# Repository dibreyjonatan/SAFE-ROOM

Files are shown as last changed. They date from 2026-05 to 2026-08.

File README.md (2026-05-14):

# SAFE-ROOM
SAFE ROOM est une dispositif électronique qui permet de connaitre en temps réel, les conditions d'une pièce. A savoir la qualité d'air, la temperature, l'humidité, et la pression.  Ce projet intègre également une antenne bluetooth qui permet de transmettre sur une platform les données capteur.

# SCHEMATIQUE DU PROJET
La schématique a été réalisé avec KiCAD 9.0
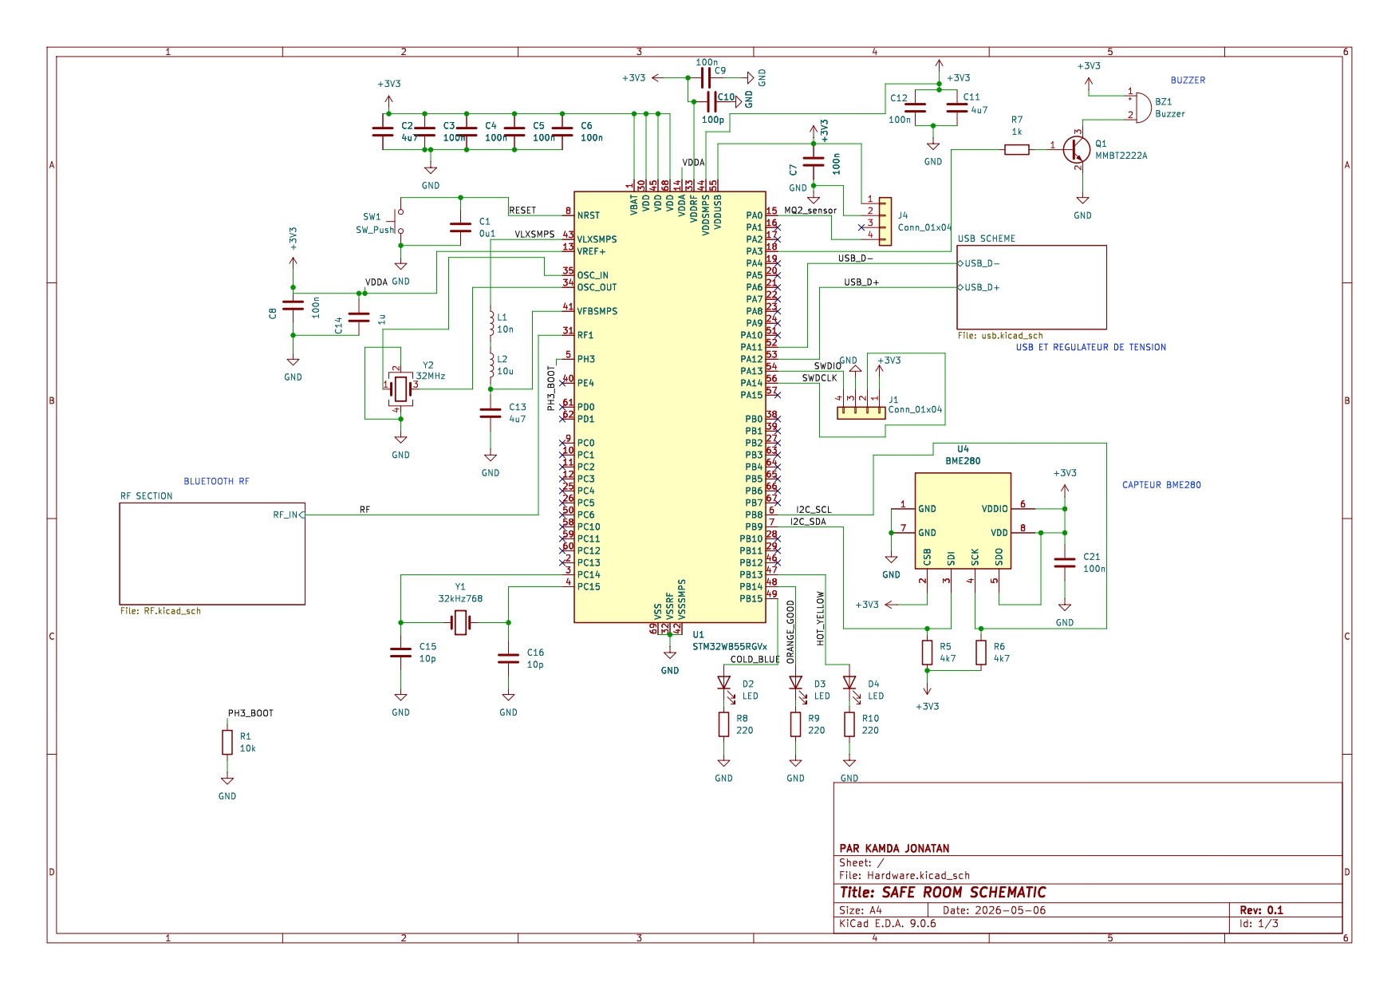
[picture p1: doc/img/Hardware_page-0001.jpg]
schematic_system

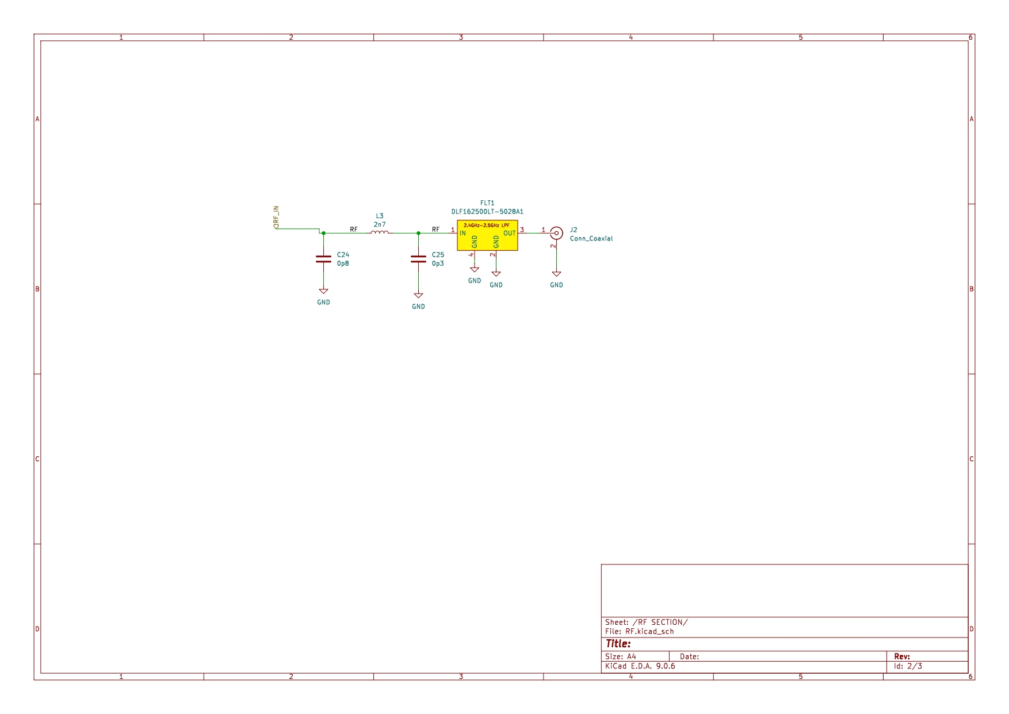
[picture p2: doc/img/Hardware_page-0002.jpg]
schematic_rf

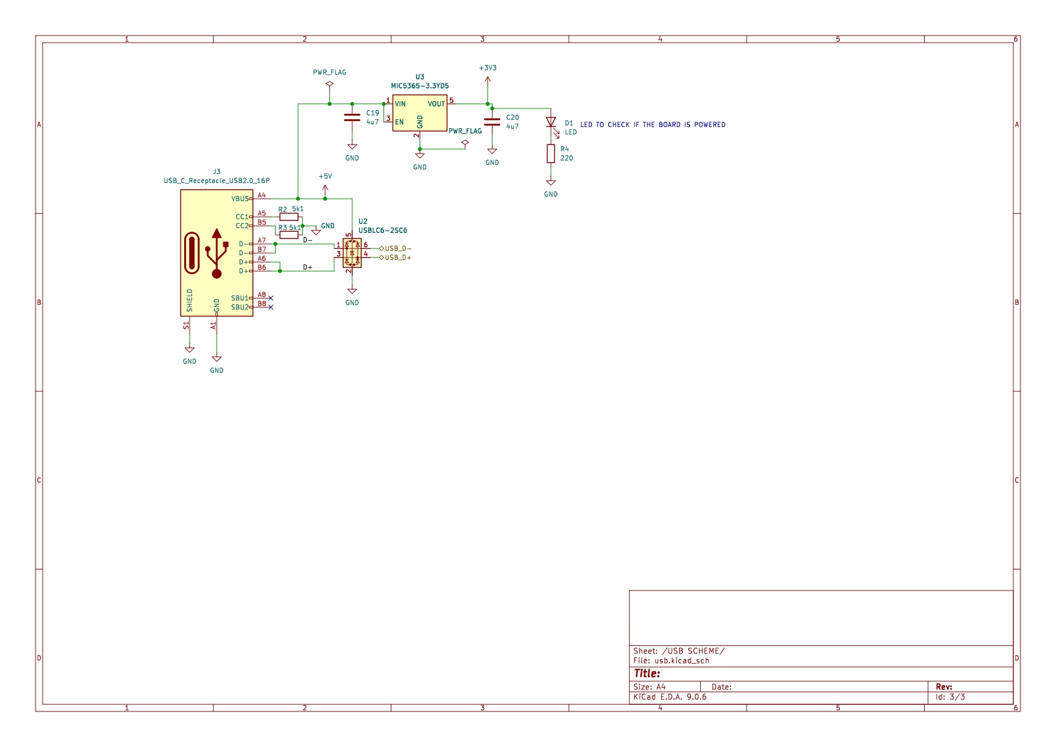
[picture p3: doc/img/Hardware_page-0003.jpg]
schematic_usb


# CARTE SAFE ROOM
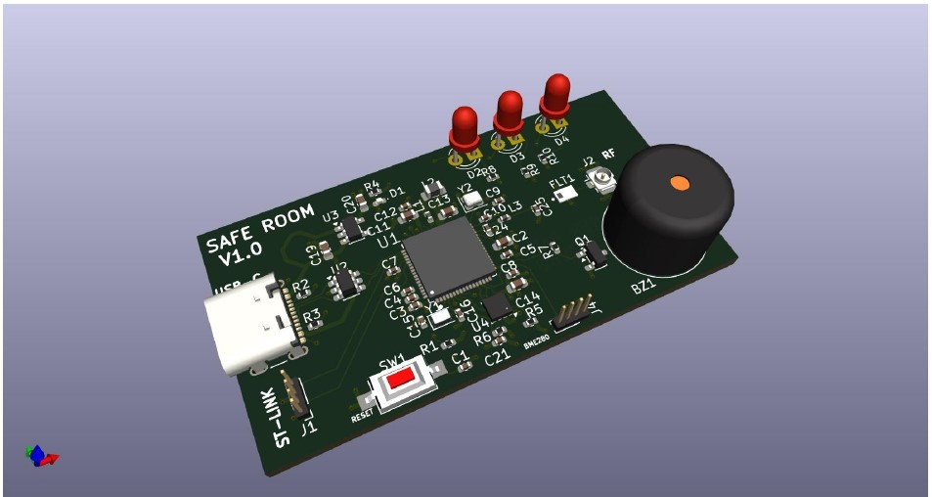
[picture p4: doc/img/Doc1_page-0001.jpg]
pcb_finale


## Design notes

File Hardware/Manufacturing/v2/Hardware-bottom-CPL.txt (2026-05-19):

### Footprint positions - created on 2026-05-17T01:28:31+0200 ###
### Printed by KiCad version 9.0.6
## Unit = mm, Angle = deg.
## Side : bottom
# Ref     Val       Package                PosX       PosY       Rot  Side
## End

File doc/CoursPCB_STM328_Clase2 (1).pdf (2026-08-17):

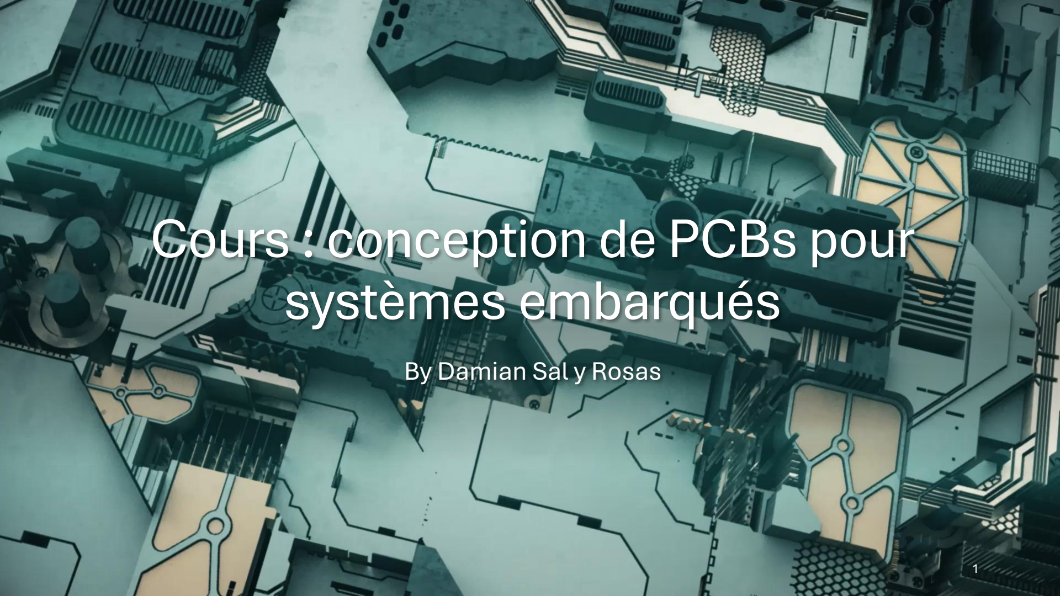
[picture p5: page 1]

# Cours : conception de PCBs pour systèmes embarqués

## By Damian Sal y Rosas

# Carte PCB à concevoir

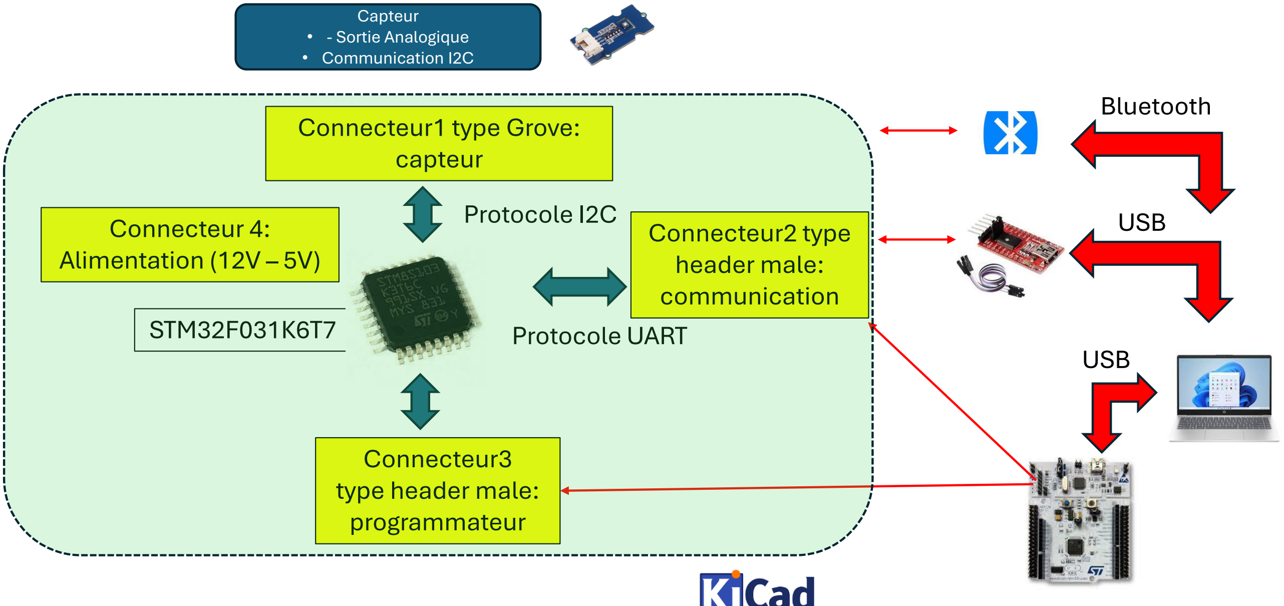
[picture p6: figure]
STM32F031K6T7; Connecteur1 type Grove: capteur; Protocole I2C; Protocole UART; Connecteur2 type header male: communication; Connecteur3 type header male: programmateur; USB; Connecteur 4: Alimentation (12V – 5V); Capteur • - Sortie Analogique • Communication I2C; Bluetooth

# Carte PCB à concevoir - Dimensionnes

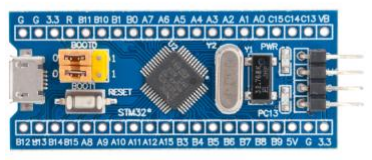
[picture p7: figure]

Connecteur 3:
programmation

Connecteur 1:
capteur

Connecteur 2:
Communication

Connecteur 4:
Power (12V-5V)

Ajouter:
- Régulateur de tension +3.3V

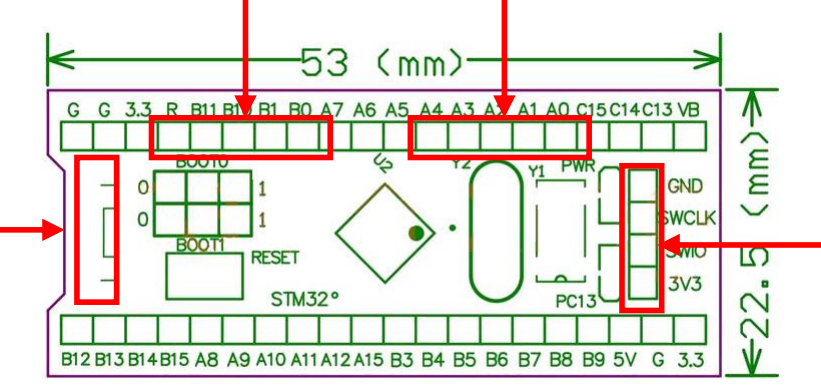
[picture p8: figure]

- LED 1 (rouge): indicateur d’alimentation
- Crystal: 8MHz
- RST (bouton poussoir 1)
- IN1 (bouton poussoir 2)
- LED2: sortie numérique

Dimensions:
- Longueur: 53mm
- Largeur: 22.5mm

# Outils pour programmer la carte

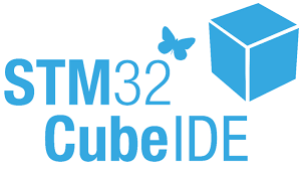
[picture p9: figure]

## STM32Cube Ide

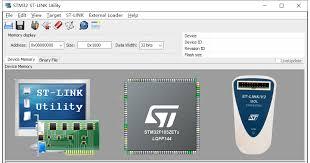
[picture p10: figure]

## STM32 ST-Link Utility

# ST-Link – Configuration externe

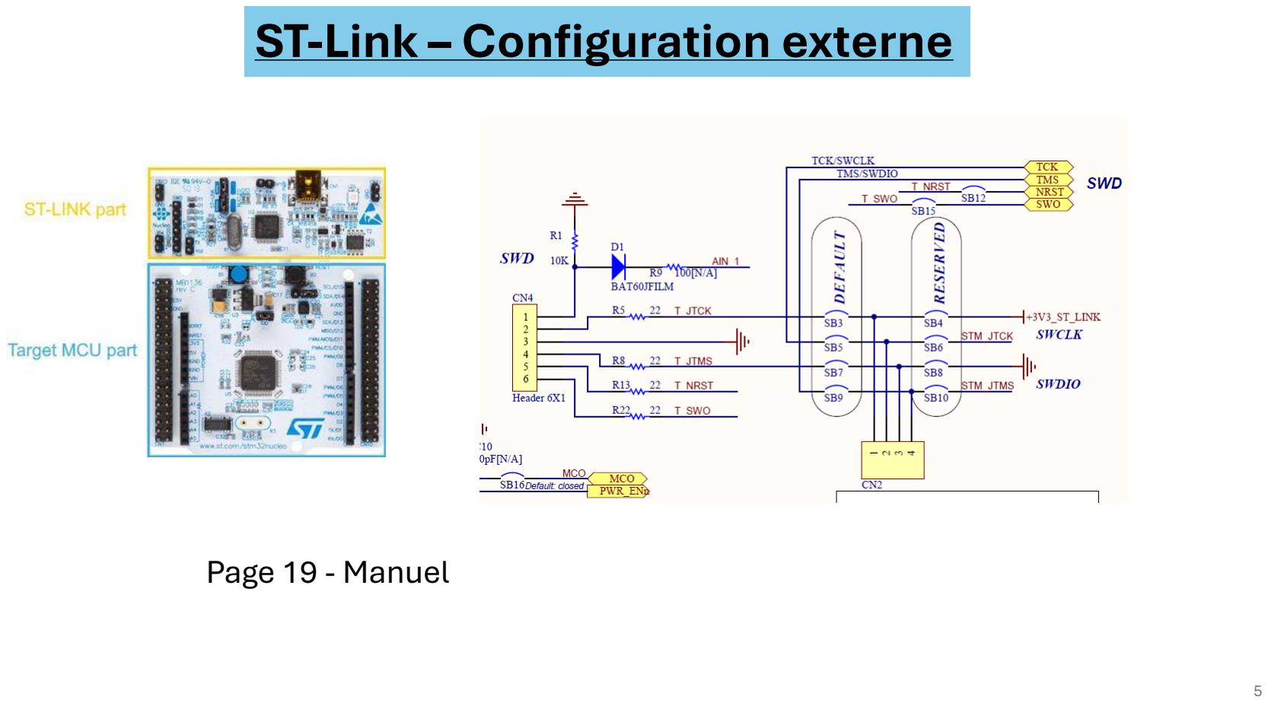
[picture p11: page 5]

## Page 19 - Manuel

# ST-Link – Configuration externe

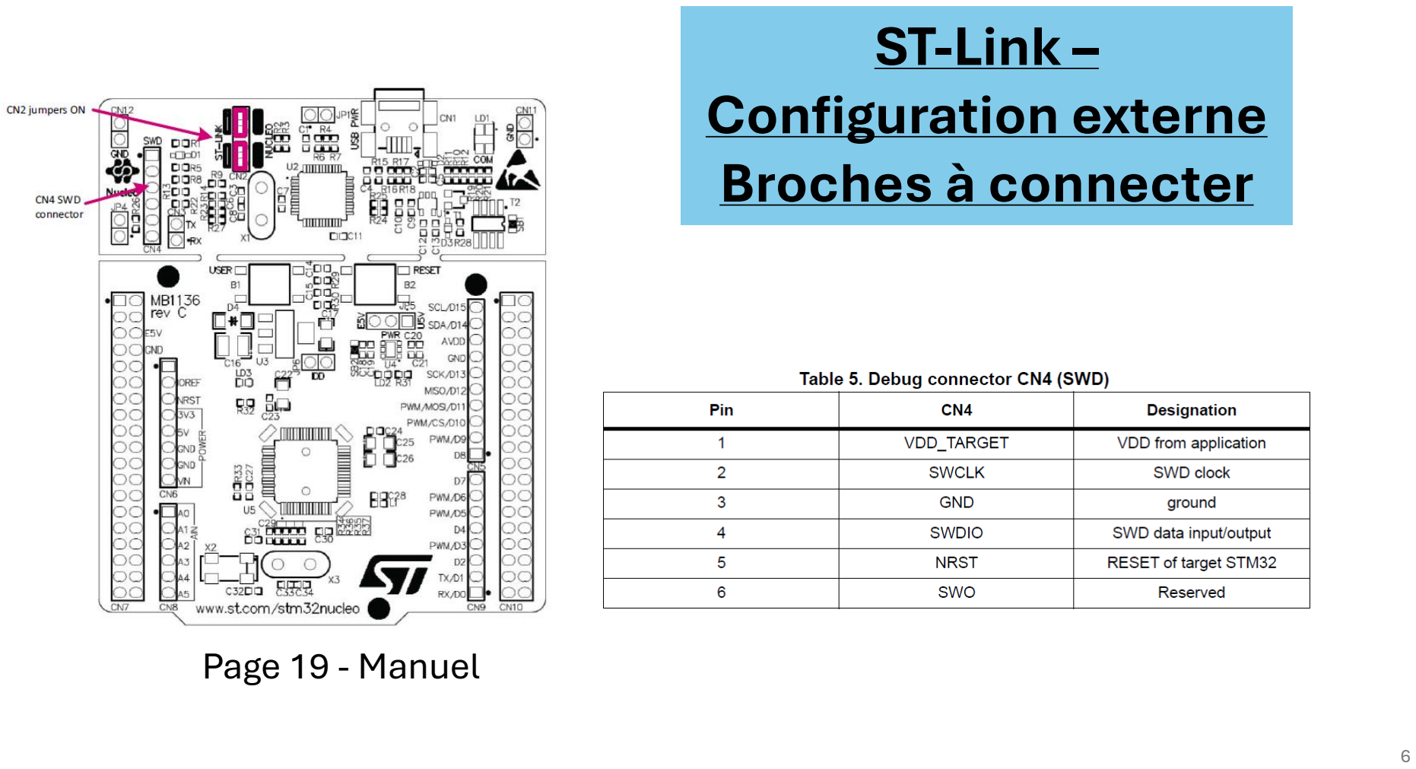
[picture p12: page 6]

# Broches à connecter

## Page 19 - Manuel

# STM32CubeIde - Configuration

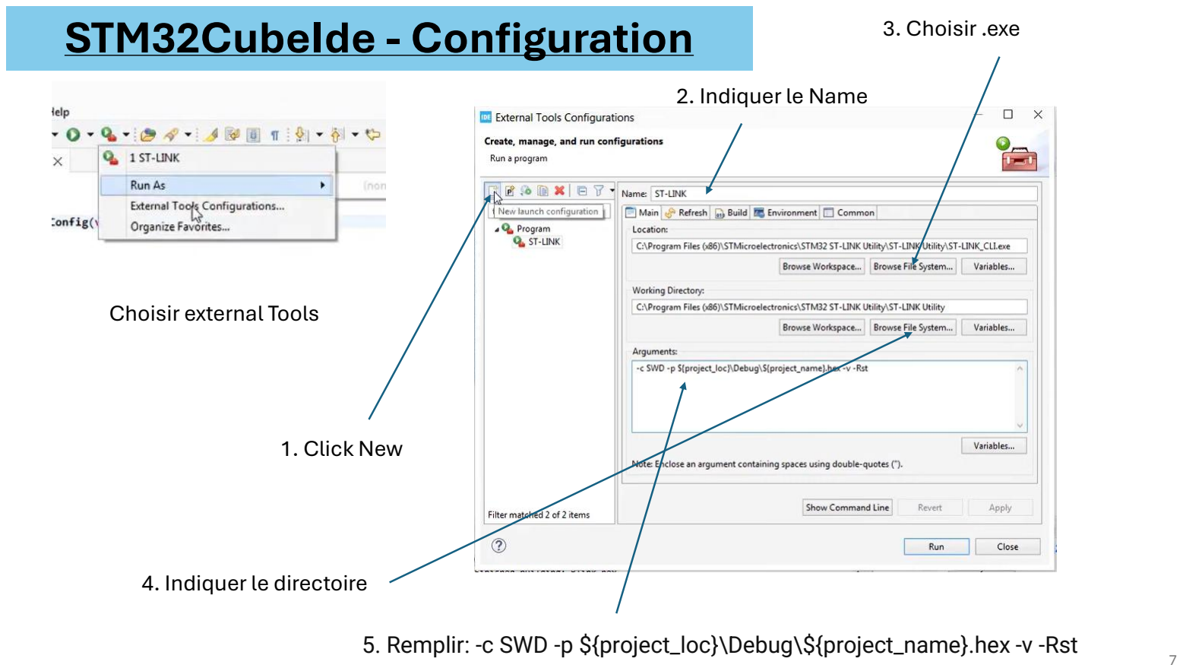
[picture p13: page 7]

Choisir external Tools

1. Click New
2. Indiquer le Name
3. Choisir .exe
4. Indiquer le directoire
5. Remplir: -c SWD -p ${project_loc}\Debug\${project_name}.hex -v -Rst

# Capteurs

# Capteur de gaz SGP30 Grove 101020512

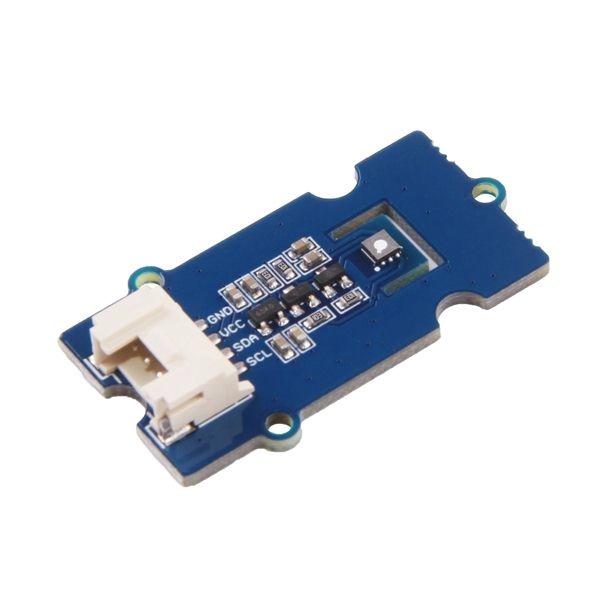
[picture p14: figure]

Caractéristiques:
- Alimentation: 3,3 à 5 Vcc
- Interface: I2C compatible Grove
- Adresse I2C: 0x58
- Plage de mesure:
- COVT: 0 à 60000 ppb (partie par milliard)
- eCO2: 400 à 60000 ppm (partie par million)
- Vitesse d’échantillonnage: 1 Hz
- Dimensions: 40 x 20 x 16 mm
- Compatible avec les supports Wrapper 1 x 2

Reference: https://www.gotronic.fr/art-capteur-de-gaz-sgp30-grove-101020512-28427.htm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

# Capteur de pression, de t° et d'humidité Grove 101020193

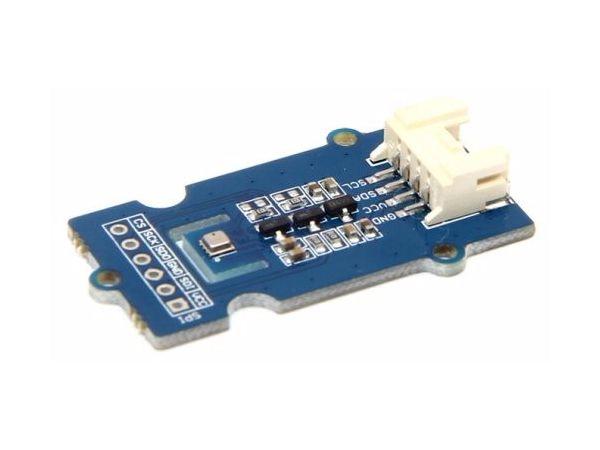
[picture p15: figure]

Ce module Grove basé sur le capteur BME280 mesure la pression, la température et l'humidité dans des plages usuelles. Il communique avec un
microcontrôleur type Arduino ou compatible via le bus I2C.

Caractéristiques:
Interface: compatible Grove
Alimentation: 3,3 à 5 Vcc
Consommation: 400 µA
Plage de mesure:
- pression: 30 à 110 kPa
- température: -40°C à +85°C Précision:
- pression: ± 1,0 hPa
- température: ±1°C
- humidité: ±3%

Reference: https://wiki.seeedstudio.com/Grove-Barometer_Sensor-BME280/?_gl=1*1dwpr65*_gcl_au*MTMyOTQyMjQzNi4xNzY4NTU2OTAy

# Capteur d'humidité Grove 101020008

Caractéristiques:

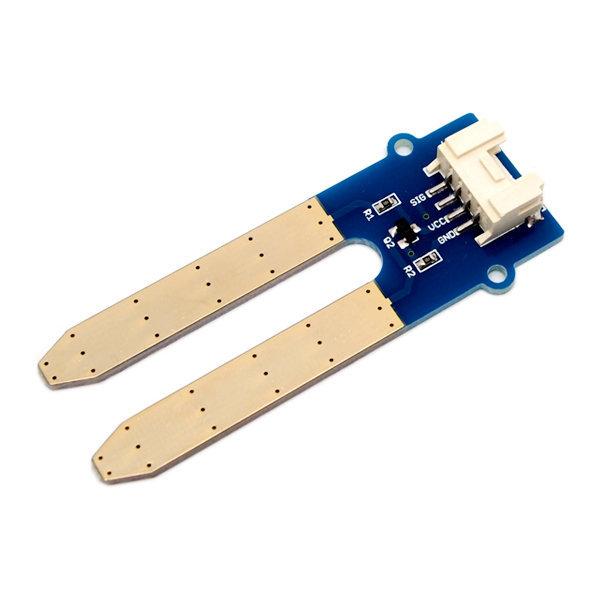
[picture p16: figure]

Ce module capteur d'humidité compatible Grove permet de connaître la concentration d'eau dans la terre par exemple. Le capteur délivre une valeur analogique en fonction de la teneur en eau.

Applications: contrôle d'humidité pour plante, détecteur d'eau etc.

Reference: https://wiki.seeedstudio.com/Grove-Moisture_Sensor/?_gl=1*1n4yam7*_gcl_au*MTMyOTQyMjQzNi4xNzY4NTU2OTAy

# Détecteur de lumière Grove V1.2 101020132

Caractéristiques:

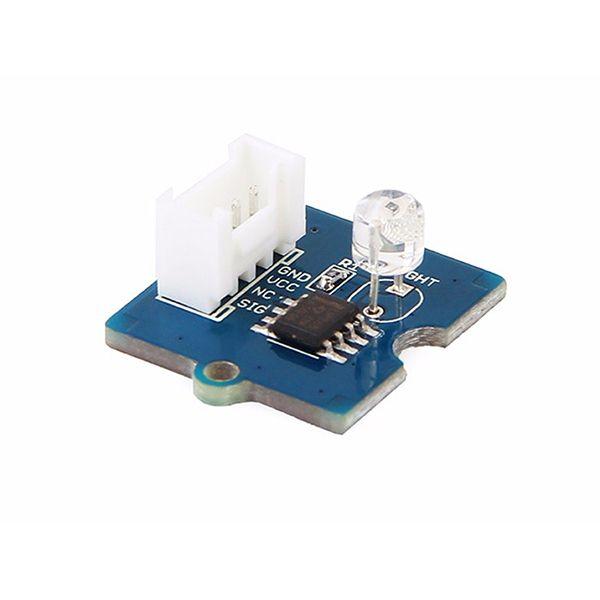
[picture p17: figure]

- Ce capteur de lumière compatible Grove utilise le phototransistor LS06-S pour détecter la présence de lumière.
- La tension de sortie analogique évolue de 0 à +Vcc en fonction de l'intensité lumineuse mesurée.

Reference: https://wiki.seeedstudio.com/Grove-Light_Sensor/?_gl=1*13zqge6*_gcl_au*MTMyOTQyMjQzNi4xNzY4NTU2OTAy

# Communication

# Module Bluetooth Grove 113020008

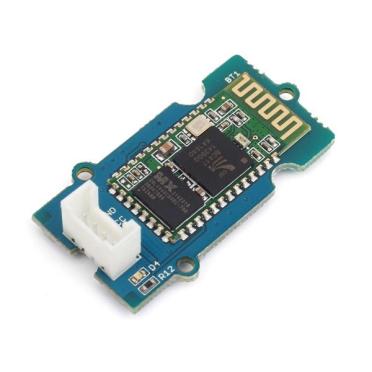
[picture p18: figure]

Module Blueseeed Serial Grove de Seeedstudio basé sur un BC417

Caractéristiques:
- Alimentation: 5 Vcc
- Bluetooth: V2.0 + EDR 3 Mbps
- Sensibilité: -80 dBm
- Puissance de transmission: +4 dBm maxi
- Interface: UART compatible Grove
- Antenne intégrée
- Dimensions: 40 x 20 x 13 mm

Reference: https://wiki.seeedstudio.com/Grove-Serial_Bluetooth_v3.0/?_gl=1*kcjcqk*_gcl_au*MTMyOTQyMjQzNi4xNzY4NTU2OTAy

# Module Bluetooth 4 HM10

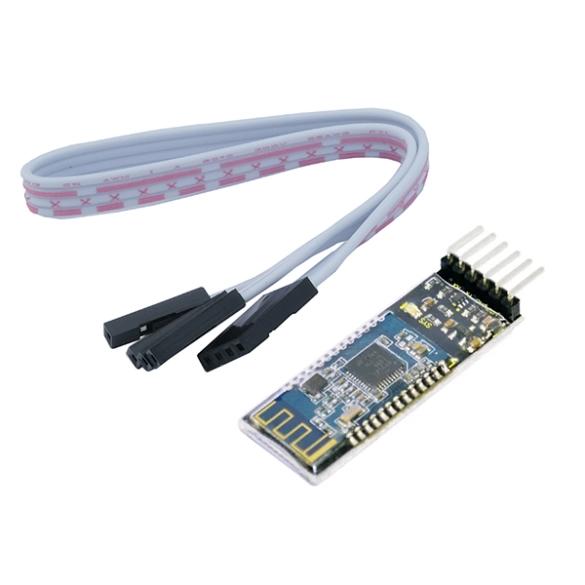
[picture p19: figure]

Le module HM10, basé sur un circuit CC2541

Caractéristiques:
Alimentation : 5 Vcc
Consommation : 50 mA
Circuit Bluetooth : CC2541
Bluetooth 4 compatible BLE (Bluetooth Low Energy) Fréquence : 2,4 GHz
Portée théorique : 100 m (en terrain dégagé) Liaison série : 9600 bps par défaut
Antenne intégrée
Broches : Vcc, Gnd, TXD, RXD, STATE et BRK Configurable via commandes AT Température de service : -5 à 65 °C
Dimensions : 27 x 13 x 2,2 mm

Reference:
https://www.ti.com/lit/ds/symlink/cc2541.pdf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 *MTMyOTQyMjQzNi4xNzY4NTU2OTAy

FT232

Convertiseur USB – RS232, sur la base du composant FT232R

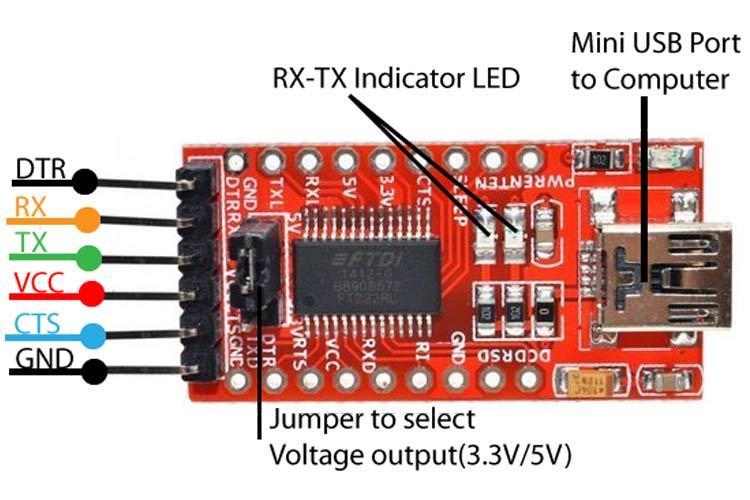
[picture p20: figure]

Reference: https://ftdichip.com/wp-content/uploads/2020/08/DS_FT232R.pdf

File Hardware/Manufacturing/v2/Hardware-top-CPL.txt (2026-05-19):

### Footprint positions - created on 2026-05-17T01:28:31+0200 ###
### Printed by KiCad version 9.0.6
## Unit = mm, Angle = deg.
## Side : top
# Ref     Val                          Package                                                       PosX       PosY       Rot  Side
BZ1       Buzzer                       Buzzer_12x9.5RM7.6                                         52.5000    10.0000  180.0000  top
C1        0u1                          C_0402_1005Metric                                          21.5200     4.5000    0.0000  top
C2        4u7                          C_0603_1608Metric                                          31.7750    16.0000    0.0000  top
C3        100n                         C_0402_1005Metric                                          19.5200    13.0000  180.0000  top
C4        100n                         C_0402_1005Metric                                          19.5200    14.0000  180.0000  top
C5        100n                         C_0402_1005Metric                                          31.5200    14.5000    0.0000  top
C6        100n                         C_0402_1005Metric                                          19.4800    15.0000  180.0000  top
C7        100n                         C_0402_1005Metric                                          19.0200    18.0000    0.0000  top
C8        100n                         C_0402_1005Metric                                          30.5000    11.5000  180.0000  top
C9        100n                         C_0402_1005Metric                                          33.9800    21.5000  180.0000  top
C10       100p                         C_0402_1005Metric                                          31.4800    20.0000  180.0000  top
C11       4u7                          C_0603_1608Metric                                          23.2750    23.5000  180.0000  top
C12       100n                         C_0402_1005Metric                                          23.4800    25.5000  180.0000  top
C13       4u7                          C_0603_1608Metric                                          27.7750    22.5000    0.0000  top
C14       1u                           C_0402_1005Metric                                          29.9800    10.5000  180.0000  top
C15       10p                          C_0402_1005Metric                                          19.5000    10.9800   90.0000  top
C16       10p                          C_0402_1005Metric                                          23.5000    10.0200  -90.0000  top
C19       4u7                          C_0603_1608Metric                                          13.5000    24.0000   90.0000  top
C20       4u7                          C_0603_1608Metric                                          19.0000    28.2250   90.0000  top
C21       100n                         C_0402_1005Metric                                          25.9800     5.5000    0.0000  top
C24       0p8                          C_0402_1005Metric                                          31.0000    18.5200  -90.0000  top
C25       0p3                          C_0402_1005Metric                                          37.4800    18.5200  -90.0000  top
D1        LED                          LED_0402_1005Metric                                        20.9850    27.5000  180.0000  top
D2        LED                          LED_D3.0mm                                                 34.5000    29.5000  180.0000  top
D3        LED                          LED_D3.0mm                                                 40.5000    29.5000  180.0000  top
D4        LED                          LED_D3.0mm                                                 47.0000    29.5000  180.0000  top
FLT1      DLF162500LT-5028A1           FIL_DEA160915LT-1169                                       41.8500    19.0000    0.0000  top
J1        Conn_01x04                   PinHeader_1x04_P2.54mm_Vertical                             4.0000     2.6900  180.0000  top
J2        Conn_Coaxial                 U.FL_Hirose_U.FL-R-SMT-1_Vertical                          46.5500    19.0000    0.0000  top
J3        USB_C_Receptacle_USB2.0_16P  USB_C_Receptacle_GCT_USB4105-xx-A_16P_TopMnt_Horizontal     3.3200    17.6000  -90.0000  top
J4        Conn_01x04                   PinHeader_1x04_P2.54mm_Vertical                            36.5000     2.5000  -90.0000  top
L1        10n                          L_0402_1005Metric                                          25.5000    23.0000   90.0000  top
L2        10u                          L_0805_2012Metric                                          26.9375    25.0000    0.0000  top
L3        2n7                          L_0402_1005Metric                                          33.4850    19.0000    0.0000  top
Q1        MMBT2222A                    SOT-23                                                     40.4375    10.0500    0.0000  top
R1        10k                          R_0402_1005Metric                                          21.0100     7.5000    0.0000  top
R2        5k1                          R_0402_1005Metric                                           9.0100    19.5000    0.0000  top
R3        5k1                          R_0402_1005Metric                                           9.0100    15.5000    0.0000  top
R4        220                          R_0402_1005Metric                                          21.0100    29.0000    0.0000  top
R5        4k7                          R_0402_1005Metric                                          30.0000     6.0000    0.0000  top
R6        4k7                          R_0402_1005Metric                                          26.5100     6.5000    0.0000  top
R7        1k                           R_0402_1005Metric                                          36.9900    13.0000   90.0000  top
R8        220                          R_0402_1005Metric                                          34.9900    25.0000    0.0000  top
R9        220                          R_0402_1005Metric                                          38.9900    24.0000  -90.0000  top
R10       220                          R_0402_1005Metric                                          41.9900    25.0000  -90.0000  top
SW1       SW_Push                      SW_SPST_CK_RS282G05A3                                      15.0000     5.5000    0.0000  top
U1        STM32WB55RGVx                QFN40P800X800X100-69N                                      25.2200    16.7900   90.0000  top
U2        USBLC6-2SC6                  SOT-23-6                                                   13.6375    18.5500    0.0000  top
U3        MIC5365-3.3YD5               TSOT-23-5                                                  16.6375    25.0500    0.0000  top
U4        BME280                       Bosch_LGA-8_2.5x2.5mm_P0.65mm_ClockwisePinNumbering        27.5250     8.9750  180.0000  top
Y1        32kHz768                     Crystal_SMD_2012-2Pin_2.0x1.2mm                            21.5000    10.5000    0.0000  top
Y2        32MHz                        Crystal_SMD_2016-4Pin_2.0x1.6mm                            31.2000    22.9500    0.0000  top
## End

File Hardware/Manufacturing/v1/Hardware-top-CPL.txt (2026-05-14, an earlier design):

### Footprint positions - created on 2026-05-14T13:10:31+0200 ###
### Printed by KiCad version 9.0.6
## Unit = mm, Angle = deg.
## Side : top
# Ref     Val                          Package                                                       PosX       PosY       Rot  Side
BZ1       Buzzer                       Buzzer_12x9.5RM7.6                                         52.5000     7.0000  180.0000  top
C1        0u1                          C_0402_1005Metric                                          21.5200     1.5000    0.0000  top
C2        4u7                          C_0603_1608Metric                                          31.7750    13.0000    0.0000  top
C3        100n                         C_0402_1005Metric                                          19.5200    10.0000  180.0000  top
C4        100n                         C_0402_1005Metric                                          19.5200    11.0000  180.0000  top
C5        100n                         C_0402_1005Metric                                          31.5200    11.5000    0.0000  top
C6        100n                         C_0402_1005Metric                                          19.4800    12.0000  180.0000  top
C7        100n                         C_0402_1005Metric                                          19.0200    15.0000    0.0000  top
C8        100n                         C_0402_1005Metric                                          30.9800     9.0000  180.0000  top
C9        100n                         C_0402_1005Metric                                          33.9800    18.5000  180.0000  top
C10       100p                         C_0402_1005Metric                                          31.4800    17.0000  180.0000  top
C11       4u7                          C_0603_1608Metric                                          23.2750    21.0000  180.0000  top
C12       100n                         C_0402_1005Metric                                          23.4800    22.5000  180.0000  top
C13       4u7                          C_0603_1608Metric                                          27.7750    19.5000    0.0000  top
C14       1u                           C_0603_1608Metric                                          30.7750     7.5000  180.0000  top
C15       10p                          C_0402_1005Metric                                          19.5000     7.9800   90.0000  top
C16       10p                          C_0402_1005Metric                                          23.5000     7.0200  -90.0000  top
C19       4u7                          C_0603_1608Metric                                          13.0000    20.7750   90.0000  top
C20       4u7                          C_0603_1608Metric                                          19.0000    25.2250   90.0000  top
C21       100n                         C_0402_1005Metric                                          25.9800     2.5000    0.0000  top
C24       0p8                          C_0402_1005Metric                                          31.0000    15.5200  -90.0000  top
C25       0p3                          C_0402_1005Metric                                          37.4800    15.5200  -90.0000  top
D1        LED                          LED_0402_1005Metric                                        20.9850    24.5000  180.0000  top
D2        LED                          LED_D3.0mm                                                 34.5000    26.5000  180.0000  top
D3        LED                          LED_D3.0mm                                                 40.5000    26.5000  180.0000  top
D4        LED                          LED_D3.0mm                                                 47.0000    26.5000  180.0000  top
FLT1      DLF162500LT-5028A1           FIL_DEA160915LT-1169                                       41.8500    16.0000    0.0000  top
J1        Conn_01x04                   PinHeader_1x04_P1.00mm_Vertical                             5.0000     4.0000  180.0000  top
J2        Conn_Coaxial                 U.FL_Hirose_U.FL-R-SMT-1_Vertical                          46.5500    16.0000    0.0000  top
J3        USB_C_Receptacle_USB2.0_16P  USB_C_Receptacle_GCT_USB4105-xx-A_16P_TopMnt_Horizontal     3.3200    14.6000  -90.0000  top
J4        Conn_01x04                   PinHeader_1x04_P1.00mm_Vertical                            35.5000     1.5000  -90.0000  top
L1        10n                          L_0402_1005Metric                                          25.5000    20.0000   90.0000  top
L2        10u                          L_0805_2012Metric                                          27.4375    23.0000    0.0000  top
L3        2n7                          L_0402_1005Metric                                          33.4850    16.0000    0.0000  top
Q1        MMBT2222A                    SOT-23                                                     40.4375     7.0500    0.0000  top
R1        10k                          R_0402_1005Metric                                          21.0100     4.5000    0.0000  top
R2        5k1                          R_0402_1005Metric                                           9.0100    16.5000    0.0000  top
R3        5k1                          R_0402_1005Metric                                           9.0100    12.5000    0.0000  top
R4        330                          R_0402_1005Metric                                          21.0100    26.0000    0.0000  top
R5        4k7                          R_0402_1005Metric                                          30.0000     3.0000    0.0000  top
R6        4k7                          R_0402_1005Metric                                          26.5100     3.5000    0.0000  top
R7        1k                           R_0402_1005Metric                                          36.9900    10.0000   90.0000  top
R8        330                          R_0402_1005Metric                                          34.9900    22.0000    0.0000  top
R9        330                          R_0402_1005Metric                                          38.9900    21.0000  -90.0000  top
R10       330                          R_0402_1005Metric                                          41.9900    22.0000  -90.0000  top
SW1       SW_Push                      SW_SPST_CK_RS282G05A3                                      15.0000     2.5000    0.0000  top
U1        STM32WB55RGVx                QFN40P800X800X100-69N                                      25.2200    13.7900   90.0000  top
U2        USBLC6-2SC6                  SOT-23-6                                                   13.6375    15.5500    0.0000  top
U3        MIC5365-3.3YD5               TSOT-23-5                                                  16.6375    22.0500    0.0000  top
U4        BME280                       Bosch_LGA-8_2.5x2.5mm_P0.65mm_ClockwisePinNumbering        27.5250     5.9750  180.0000  top
Y1        32kHz768                     Crystal_SMD_2012-2Pin_2.0x1.2mm                            21.5000     7.5000    0.0000  top
Y2        32MHz                        Crystal_SMD_2016-4Pin_2.0x1.6mm                            31.2000    19.9500    0.0000  top
## End

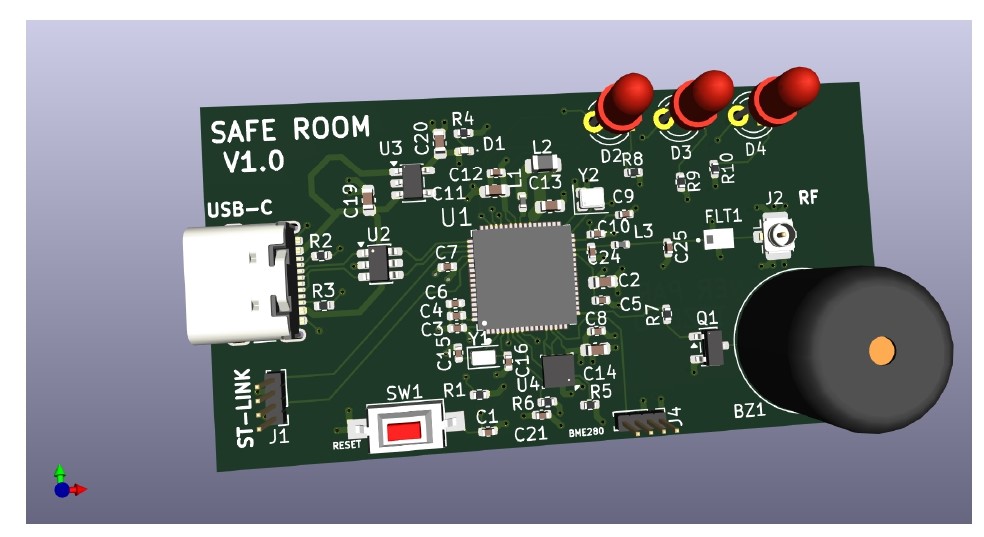
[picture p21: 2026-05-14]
doc/img/Doc1_page-0002.jpg

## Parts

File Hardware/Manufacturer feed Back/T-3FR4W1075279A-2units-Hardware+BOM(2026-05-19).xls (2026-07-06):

PCBWay Bom Quotation, Product No.:T-3FR4W1075279A
Item # | *Designator | *Qty | Manufacturer | *Mfg Part # | Description / Value | *Package/Footprint | Your Instructions / Notes | *Unit Price(2 units) | *Total | *Delivery Time | *Actual Purchase Mfg Part # | *PCBWay Note | Customer Reply | PCBWay Update
1 | BZ1 | 1 | Same Sky | CMI-1295-85T | Buzzer | Buzzer_Beeper:Buzzer_12x9.5RM7.6 | https://www.mouser.fr/datasheet/3/6118/1/cmi_1295_85t.pdf | $6.629 | $13.258 | 7-10 Workdays
2 | C1 | 1 | KYOCERA AVX | 04023C104KAT2A | 0u1 | Capacitor_SMD:C_0402_1005Metric | https://datasheets.kyocera-avx.com/KGM_X7R.pdf | $0.189 | $0.378
3 | C2,C11,C13,C19,C20 | 5 | KYOCERA AVX | 0603YD475MAT2A | 4u7 | Capacitor_SMD:C_0603_1608Metric | https://datasheets.kyocera-avx.com/cx5r.pdf | $0.347 | $3.470
4 | C3,C4,C5,C6,C7,C8,C9,C12,C21 | 9 | KYOCERA AVX | 04023C104KAT2A | 100n | Capacitor_SMD:C_0402_1005Metric | https://datasheets.kyocera-avx.com/KGM_X7R.pdf | $0.189 | $3.402
5 | C10 | 1 | KYOCERA AVX | 04025A101JAT2A | 100p | Capacitor_SMD:C_0402_1005Metric | https://datasheets.kyocera-avx.com/C0GNP0-KGM.pdf | $0.347 | $0.694
6 | C14 | 1 | Murata Electronics | GRM155R61E105KA12D | 1u | Capacitor_SMD:C_0402_1005Metric | https://www.mouser.fr/datasheet/3/76/1/GRM155R61E105KA12-01A.pdf | $0.347 | $0.694
7 | C15,C16 | 2 | KYOCERA AVX | 04025A100JAT4A | 10p | Capacitor_SMD:C_0402_1005Metric | https://datasheets.kyocera-avx.com/C0GNP0-KGM.pdf | $0.189 | $0.756
8 | C24 | 1 | Vishay / Vitramon | VJ0402D0R8VXBAJHT | 0p8 | Capacitor_SMD:C_0402_1005Metric | https://www.vishay.com/docs/45239/vjhifreqht.pdf | $3.665 | $7.330 | 7-10 Workdays
9 | C25 | 1 | Murata Electronics | GRM1555C1HR30WA01D | 0p3 | Capacitor_SMD:C_0402_1005Metric | https://pim.murata.com/asset/pim4/ceramicCapacitorSMD/GRM1555C1HR30WA01-01A-EN_PDF_CERAMICCAPACITORSMD | $0.347 | $0.694
10 | D1 | 1 | Wurth Elektronik | 150040RS73240 | LED | LED_SMD:LED_0402_1005Metric | https://www.we-online.com/components/products/datasheet/150040RS73240.pdf | $0.755 | $1.510
11 | D2 | 1 | Kingbright,Kingbright | WP7113ND,WP7113QBC/D,WP7113SYD | LED | LED_THT:LED_D3.0mm | https://www.mouser.fr/ProductDetail/Kingbright/WP7113ND | $1.187 | $2.374 | 7-10 Workdays | WP7113QBC/D |  | There are 3 different led, with each having a manufacturer part number as follows : D2 is WP7113QBC/D, D3 is WP7113ND and D4 is WP7113SYD.
12 | FLT1 | 1 | TDK | DLF162500LT-5028A1 | DLF162500LT-5028A1 | my_personnal_Library_footprint:FIL_DEA160915LT-1169 | https://product.tdk.com/system/files/dam/doc/product/rf/rf/filter/catalog/rf_lpf_dlf162500lt-5028a1_en.pdf | $0.755 | $1.510
13 | J1,J4 | 2 | SAMTEC | TSW-112-07-TM-S | Conn_01x04 | Connector_PinHeader_2.54mm:PinHeader_1x04_P2.54mm_Vertical | https://www.snapeda.com/parts/TSW-112-07-TM-S/Samtec/datasheet/ | $1.524 | $6.096 | 7-10 Workdays |  | it's 2*2*$1.524 | There is a calculation error here please, how can 2*$1.524 be equal to $6,096 ?; If not the case, one may be sufficient in assembly right ?
14 | J2 | 1 | Hirose Connector | U.FL-R-SMT(01) | Conn_Coaxial | Connector_Coaxial:U.FL_Hirose_U.FL-R-SMT-1_Vertical | https://www.mouser.com/catalog/specsheets/hiros04491-1.pdf | $0.604 | $1.208
15 | J3 | 1 | GCT | USB4105-GF-A | USB_C_Receptacle_USB2.0_16P | Connector_USB:USB_C_Receptacle_GCT_USB4105-xx-A_16P_TopMnt_Horizontal | https://www.usb.org/sites/default/files/documents/usb_type-c.zip | $1.660 | $3.320
16 | L1 | 1 | Murata Electronics | LQG15WZ10NJ02D | 10n | Inductor_SMD:L_0402_1005Metric | https://www.mouser.fr/datasheet/3/76/2/JELF243B_9117.pdf | $0.235 | $0.470 | 7-10 Workdays
17 | L2 | 1 | Murata Electronics | LQM21FN100M70L | 10u | Inductor_SMD:L_0805_2012Metric | https://www.mouser.fr/datasheet/3/76/2/JELF243B_0011.pdf | $1.434 | $2.868
18 | L3 | 1 | Murata Electronics | LQG15HS2N7S02D | 2n7 | Inductor_SMD:L_0402_1005Metric | https://www.mouser.fr/datasheet/3/76/2/JELF243B_0010.pdf | $0.235 | $0.470 | 7-10 Workdays
19 | Q1 | 1 | Diotec Semiconductor | MMBT2222A | MMBT2222A | Package_TO_SOT_SMD:SOT-23 | https://assets.nexperia.com/documents/data-sheet/MMBT2222A.pdf | $0.258 | $0.516 | 7-10 Workdays
20 | R1 | 1 | YAGEO | RC0402BR-0710KL | 10k | Resistor_SMD:R_0402_1005Metric | https://www.mouser.fr/datasheet/3/508/1/PYu-RC_Group_51_RoHS_L_12.pdf | $0.347 | $0.694
21 | R2,R3 | 2 | YAGEO | RC0402BR-075K1L | 5k1 | Resistor_SMD:R_0402_1005Metric | https://www.mouser.fr/ProductDetail/YAGEO/RC0402BR-075K1L?qs=eP2BKZSCXI5z8A6ic6YLjQ%3D%3D | $0.189 | $0.756
22 | R4,R8,R9,R10 | 4 | YAGEO | RC0402FR-07221RL | 220 | Resistor_SMD:R_0402_1005Metric | https://www.mouser.com/catalog/specsheets/YAGEO_PYu_RC_Group_51_RoHS_L_12.pdf | $0.022 | $0.176
23 | R5,R6 | 2 | YAGEO | RC0402BR-074K7L | 4k7 | Resistor_SMD:R_0402_1005Metric | https://snapeda.s3.amazonaws.com/datasheet/Yageo_RC_Series_Resistor.pdf | $0.189 | $0.756
24 | R7 | 1 | YAGEO | RC0402BR-071KL | 1k | Resistor_SMD:R_0402_1005Metric | https://www.snapeda.com/parts/RC0402BR-071KL/Yageo/view-part/?ref=mouser | $0.347 | $0.694
25 | SW1 | 1 | C&K | RS-282G05A3-SM RT | SW_Push | Button_Switch_SMD:SW_SPST_CK_RS282G05A3 | https://www.mouser.com/catalog/specsheets/RS-282G05A-SM_RT.pdf | $2.203 | $4.406 | 7-10 Workdays
26 | U1 | 1 | STMicroelectronics | STM32WB55RGV6 | STM32WB55RGVx | my_personnal_Library_footprint:QFN40P800X800X100-69N | https://www.st.com/resource/en/datasheet/stm32wb55cc.pdf | $13.645 | $27.290
27 | U2 | 1 | STMicroelectronics | USBLC6-2SC6 | USBLC6-2SC6 | Package_TO_SOT_SMD:SOT-23-6 | https://www.st.com/resource/en/datasheet/usblc6-2.pdf | $0.302 | $0.604
28 | U3 | 1 | Microchip Technology | MIC5365-3.3YD5-TR | MIC5365-3.3YD5 | Package_TO_SOT_SMD:TSOT-23-5 | https://ww1.microchip.com/downloads/aemDocuments/documents/APID/ProductDocuments/DataSheets/MIC5365-6-High-Performance-Single-150mA-LDO-DS20006605A.pdf | $2.264 | $4.528
29 | U4 | 1 | Bosch Sensortec | BME280 | BME280 | Package_LGA:Bosch_LGA-8_2.5x2.5mm_P0.65mm_ClockwisePinNumbering | https://www.bosch-sensortec.com/media/boschsensortec/downloads/datasheets/bst-bme280-ds002.pdf | $5.031 | $10.062
30 | Y1 | 1 | NDK | NX2012SA-32.768K-STD-MUB-1 | 32kHz768 | Crystal:Crystal_SMD_2012-2Pin_2.0x1.2mm | https://www.mouser.fr/datasheet/3/1591/1/NDKX01_00006_en.pdf | $1.147 | $2.294
31 | Y2 | 1 | NDK | NX2016SA-32M-EXS00A-CS06465 | 32MHz | Crystal:Crystal_SMD_2016-4Pin_2.0x1.6mm | https://www.ndk.com/en/products/upload/lineup/pdf/NDKX03-00015_en.pdf | $1.057 | $2.114
32 | D3 | 1 |  | WP7113ND |  |  |  | $1.235 | $2.470 | 7-10 Workdays
33 | D4 | 1 |  | WP7113SYD |  |  |  | $1.759 | $3.518 | 7-10 Workdays
 |  |  |  |  |  |  |  | Component Cost | $111.38
 |  |  |  |  |  |  |  | Assembly Cost | $29.00
 |  |  |  |  |  |  |  | PCB Cost | $25.97
 |  |  |  |  |  |  |  | V0 Member 0% off | $0.00
 |  |  |  |  |  |  |  | All Total 2 Units | $166.35

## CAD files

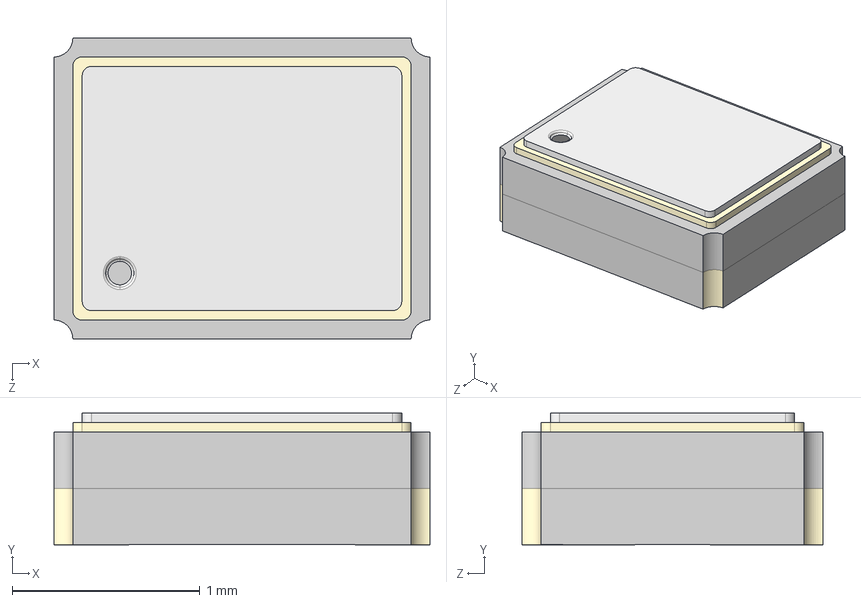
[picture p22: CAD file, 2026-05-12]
Hardware/Model 3D/User Library-NT2016SA-END4910A-48MHZ Crystal (NDK).step
2.00 x 0.701 x 1.60 mm

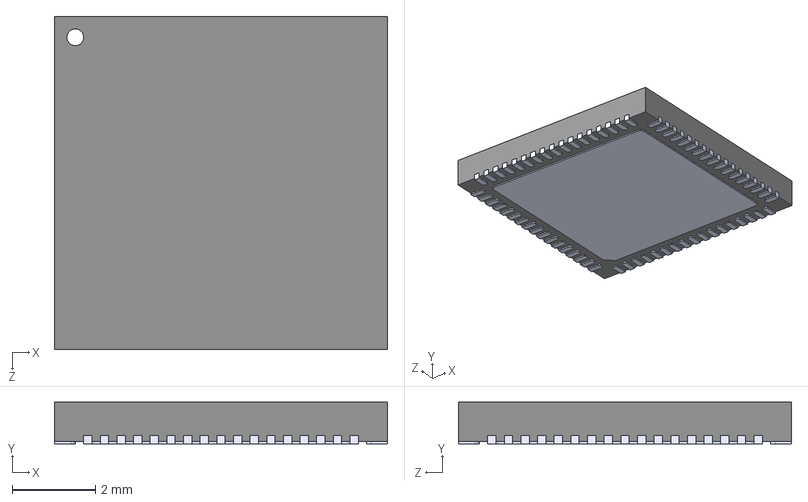
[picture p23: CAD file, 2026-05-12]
Hardware/Model 3D/STM32WB55RGV7--3DModel-STEP-510211.STEP
8.00 x 1.00 x 8.00 mm

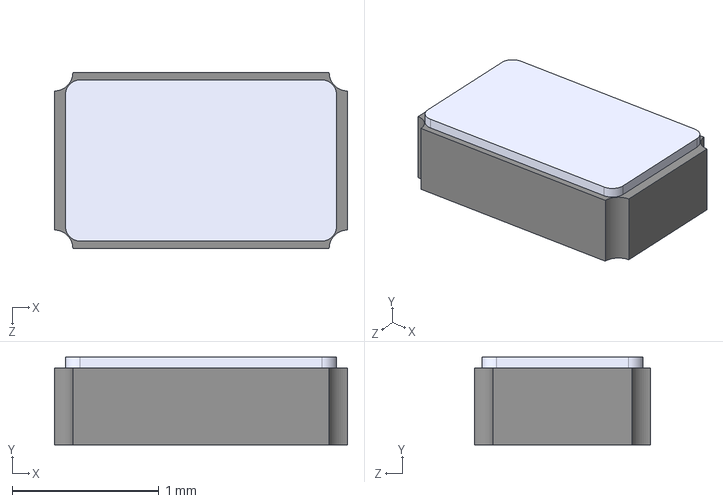
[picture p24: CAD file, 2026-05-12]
Hardware/Model 3D/CM8V-T1A-32.768KHZ-7PF-10PPM-TA-QC.STEP
2.00 x 0.6 x 1.20 mm

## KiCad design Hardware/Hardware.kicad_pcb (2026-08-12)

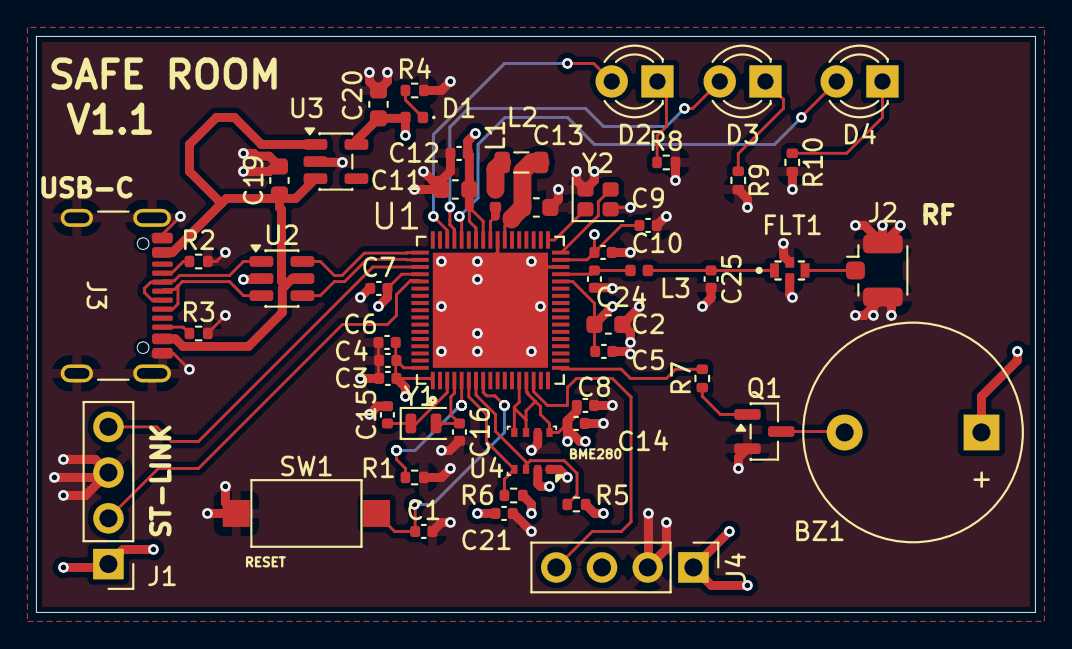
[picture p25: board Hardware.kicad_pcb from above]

Board: 4 copper layers, 55.5 x 32.0 mm, 52 parts (0 on the bottom side), 36 nets.

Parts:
BZ1: Buzzer; Buzzer_12x9.5RM7.6
C1: 0u1; C_0402_1005Metric
C2, C11, C13, C19, C20: 4u7; C_0603_1608Metric
C3, C4, C5, C6, C7, C8, C9, C12, C21: 100n; C_0402_1005Metric
C10: 100p; C_0402_1005Metric
C14: 1u; C_0402_1005Metric
C15, C16: 10p; C_0402_1005Metric
C24: 0p8; C_0402_1005Metric
C25: 0p3; C_0402_1005Metric
D1: LED; LED_0402_1005Metric
D2, D3, D4: LED; LED_D3.0mm
FLT1: DLF162500LT-5028A1; FIL_DEA160915LT-1169
J1, J4: Conn_01x04; PinHeader_1x04_P2.54mm_Vertical
J2: Conn_Coaxial; U.FL_Hirose_U.FL-R-SMT-1_Vertical
J3: USB_C_Receptacle_USB2.0_16P; USB_C_Receptacle_GCT_USB4105-xx-A_16P_TopMnt_Horizontal
L1: 10n; L_0402_1005Metric
L2: 10u; L_0805_2012Metric
L3: 2n7; L_0402_1005Metric
Q1: MMBT2222A; SOT-23
R1: 10k; R_0402_1005Metric
R2, R3: 5k1; R_0402_1005Metric
R4, R8, R9, R10: 220; R_0402_1005Metric
R5, R6: 4k7; R_0402_1005Metric
R7: 1k; R_0402_1005Metric
SW1: SW_Push; SW_SPST_CK_RS282G05A3
U1: STM32WB55RGVx; QFN40P800X800X100-69N
U2: USBLC6-2SC6; SOT-23-6
U3: MIC5365-3.3YD5; TSOT-23-5
U4: BME280; Bosch_LGA-8_2.5x2.5mm_P0.65mm_ClockwisePinNumbering
Y1: 32kHz768; Crystal_SMD_2012-2Pin_2.0x1.2mm
Y2: 32MHz; Crystal_SMD_2016-4Pin_2.0x1.6mm

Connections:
+3V3: BZ1.1 (+), C2.1, C3.1, C4.1, C5.1, C6.1, C7.2, C8.2, C9.2, C10.2, C11.1, C12.1, C14.2, C20.1, C21.1, D1.2 (A), J1.1, J4.1, R5.2, R6.2, U1.1 (VBAT), U1.13 (VREF+), U1.14 (VDDA), U1.30 (VDD), U1.33 (VDDRF), U1.44 (VDDSMPS), U1.45 (VDD), U1.55 (VDDUSB), U1.68 (VDD), U3.5 (VOUT), U4.2 (CSB), U4.5 (SDO), U4.6 (VDDIO), U4.8 (VDD)
+5V: C19.1, J3.A4 (VBUS), J3.A9 (VBUS), J3.B4 (VBUS), J3.B9 (VBUS), U2.5 (VBUS), U3.1 (VIN), U3.3 (EN)
/COLD_BLUE: D2.2 (A), U1.49 (PB15)
/HOT_YELLOW: D4.2 (A), U1.47 (PB13)
/I2C_SCL: R6.1, U1.6 (PB8), U4.4 (SCK)
/I2C_SDA: R5.1, U1.7 (PB9), U4.3 (SDI)
/MQ2_sensor: J4.4, U1.15 (PA0)
/ORANGE_GOOD: D3.2 (A), U1.48 (PB14)
/PH3_BOOT: R1.1, U1.5 (PH3)
/RESET: C1.1, SW1.2, U1.8 (NRST)
/RF: C24.1, L3.1, U1.31 (RF1)
/SWDCLK: J1.2, U1.56 (PA14)
/SWDIO: J1.4, U1.54 (PA13)
/USB SCHEME/D+: J3.A6 (D+), J3.B6 (D+), U2.3 (I/O2)
/USB SCHEME/D-: J3.A7 (D-), J3.B7 (D-), U2.1 (I/O1)
/USB_D+: U1.53 (PA12), U2.4 (I/O2)
/USB_D-: U1.52 (PA11), U2.6 (I/O1)
/VLXSMPS: L1.1, U1.43 (VLXSMPS)
GND: C1.2, C2.2, C3.2, C4.2, C5.2, C6.2, C7.1, C8.1, C9.1, C10.1, C11.2, C12.2, C13.2, C14.1, C15.2, C16.2, C19.2, C20.2, C21.2, C24.2, C25.2, FLT1.2 (GND), FLT1.4 (GND), J1.3, J2.2 (Ext), J3.A1 (GND), J3.A12 (GND), J3.B1 (GND), J3.B12 (GND), J3.S1 (SHIELD), J4.2, Q1.2 (E), R1.2, R2.2, R3.2, R4.2, R8.2, R9.2, R10.2, SW1.1, U1.32 (VSSRF), U1.42 (VSSSMPS), U1.69 (VSS), U2.2 (GND), U3.2 (GND), U4.1 (GND), U4.7 (GND), Y2.2, Y2.4
unnamed: BZ1.2 (-), Q1.3 (C)
unnamed: D1.1 (K), R4.1
unnamed: D2.1 (K), R8.1
unnamed: D3.1 (K), R9.1
unnamed: D4.1 (K), R10.1
unnamed: C25.1, FLT1.1 (IN), L3.2
unnamed: FLT1.3 (OUT), J2.1 (In)
unnamed: J3.A5 (CC1), R2.1
unnamed: J3.B5 (CC2), R3.1
unnamed: L1.2, L2.1
unnamed: Q1.1 (B), R7.1
unnamed: U1.35 (OSC_IN), Y2.1
unnamed: U1.34 (OSC_OUT), Y2.3
unnamed: R7.2, U1.18 (PA3)
unnamed: C15.1, U1.3 (PC14), Y1.1
unnamed: C16.1, U1.4 (PC15), Y1.2
unnamed: C13.1, L2.2, U1.41 (VFBSMPS)

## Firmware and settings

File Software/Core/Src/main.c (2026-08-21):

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
/* Includes ------------------------------------------------------------------*/
#include "main.h"
#include "i2c.h"
#include "ipcc.h"
#include "memorymap.h"
#include "rf.h"
#include "rtc.h"
#include "tim.h"
#include "usb_device.h"
#include "gpio.h"

/* USER CODE BEGIN Includes */
#include "usbd_cdc_if.h"
#include "BME280_STM32.h"
/* USER CODE END Includes */

/* USER CODE BEGIN PD */
#define TIM_FREQ 32000000
/* USER CODE END PD */


void SystemClock_Config(void);
void PeriphCommonClock_Config(void);
/* USER CODE BEGIN PFP */
void noTone (void);
int presForFrequency (int frequency);
/* USER CODE END PFP */

/* USER CODE BEGIN 0 */
float Temperature, Pressure, Humidity;
/* USER CODE END 0 */

/**
  * @brief  The application entry point.
  * @retval int
  */
int main(void)
{

  /* MCU Configuration--------------------------------------------------------*/

  /* Reset of all peripherals, Initializes the Flash interface and the Systick. */
  HAL_Init();
  /* Config code for STM32_WPAN (HSE Tuning must be done before system clock configuration) */
  MX_APPE_Config();

  /* Configure the system clock */
  SystemClock_Config();

  /* Configure the peripherals common clocks */
  PeriphCommonClock_Config();

  /* IPCC initialisation */
  MX_IPCC_Init();

  /* Initialize all configured peripherals */
  MX_GPIO_Init();
  MX_USB_Device_Init();
  MX_I2C1_Init();
  MX_TIM2_Init();
  MX_RTC_Init();
  MX_RF_Init();
  /* USER CODE BEGIN 2 */
  // j'ai utilisé ca pour faire un debug, afin de visualiser la valeur de retour
 //int t=BME280_Config(OSRS_2, OSRS_16, OSRS_1, MODE_NORMAL, T_SB_0p5, IIR_16) ;
  if (BME280_Config(OSRS_2, OSRS_16, OSRS_1, MODE_NORMAL, T_SB_0p5, IIR_16) != 0)
   {
 	  Error_Handler();
   }
 // __HAL_TIM_SET_PRESCALER(&htim2,133); // pour avoir 240Hz
  HAL_TIM_PWM_Start(&htim2, TIM_CHANNEL_4);
  /* USER CODE END 2 */

  /* Init code for STM32_WPAN */
  MX_APPE_Init();

  /* Infinite loop */
  /* USER CODE BEGIN WHILE */
  while (1)
  {
    /* USER CODE END WHILE */
    MX_APPE_Process();

    /* USER CODE BEGIN 3 */
	  char msg[128];

	  BME280_Measure(&Temperature, &Pressure, &Humidity);

	  int len=snprintf(msg, sizeof(msg),
	           "Temperature: %.2f C | Pressure: %.2f Pa | Humidity: %.2f %%\r\n",
	           Temperature,
	           Pressure,
	           Humidity);

	  CDC_Transmit_FS((uint8_t *)msg, len);

	  HAL_Delay(1000);
	   // si Temp < 20 --> blue toggle
	  if ( Temperature <= 20)
	  HAL_GPIO_TogglePin(GPIOB,GPIO_PIN_15);
	  else{


	  // si Temp > 20 && Temp < 40 --> Yellow Toggle
		  if ( Temperature > 20 && Temperature <= 40)
	  HAL_GPIO_TogglePin(GPIOB,GPIO_PIN_13);
	  // si Temp > 40 --> Orange Toggle
		  else
	  HAL_GPIO_TogglePin(GPIOB,GPIO_PIN_14);
	  }
       if ( Temperature > 30){
	  __HAL_TIM_SET_PRESCALER(&htim2, presForFrequency(970));
	  HAL_Delay(80);
	  __HAL_TIM_SET_PRESCALER(&htim2, presForFrequency(770));
	  HAL_Delay(80);
	  __HAL_TIM_SET_PRESCALER(&htim2, presForFrequency(970));
	  HAL_Delay(80);
	  __HAL_TIM_SET_PRESCALER(&htim2, presForFrequency(770));
	  HAL_Delay(400);
       }else{
    	   noTone();
       }

  }
  /* USER CODE END 3 */
}

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
/* USER CODE BEGIN 4 */
int presForFrequency (int frequency)
{
	if (frequency == 0) return 0;
	return ((TIM_FREQ/(1000*frequency))-1);  // 1 is added in the register
}

void noTone (void)
{
	__HAL_TIM_SET_PRESCALER(&htim2, 0);
}
/* USER CODE END 4 */
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


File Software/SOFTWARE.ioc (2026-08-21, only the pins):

Mcu.UserName=STM32WB55RGVx
PA11.Signal=USB_DM
PA12.Signal=USB_DP
PA3.Signal=S_TIM2_CH4
PB13.Signal=GPIO_Output
PB14.Signal=GPIO_Output
PB15.Signal=GPIO_Output
PB8.Signal=I2C1_SCL
PB9.Signal=I2C1_SDA
PC14-OSC32_IN.Signal=RCC_OSC32_IN
PC15-OSC32_OUT.Signal=RCC_OSC32_OUT

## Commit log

2026-05-05 [Démarrage]: Création des fichiers de schématique dans KiCAD
    [Hardware.kicad_pcb, Hardware.kicad_sch]
2026-05-06 [Nettoyage] : J'enlève des fichiers autogénéré par KiCaD
2026-05-06 [Ajout] : Ajout du microcontrolleur STM32WB55RG utilisé dans le projet
    [Hardware.kicad_sch]
2026-05-06 [ST-LINK CONNEXION] : Ajout de la connexion ST-LINK pour téléverser le programme finale, il faut une connexion ST-LINK. La pin PA13 c'est pour la data ( SWDIO) La pin PA14 c'est pour l'horloge (SWCLK)
    [Hardware.kicad_sch]
2026-05-06 [RESET]: Ajout du bouton reset et de la capacité pour filtrer les oscillations du bouton
    [Hardware.kicad_sch]
2026-05-07 [DOCUMENTATION] : Documentation officielle de ST Microelectronics qui sert de guide pour la réalisation du système
2026-05-07 [PARTIE ALIMENTATION] : Mise en place des condensateur de découplage pour les alimentations VDD, VBAT, VDDA, VREF, VDDRF et VDSMPS. Les consignes des valeurs des condensateur de découplage sont donné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
    [Hardware.kicad_sch]
2026-05-07 [Ajout des montages d'Oscillateurs et du Montage RF] Pour concevoir les montages d'oscillateur on utilise le document applicative de ST. Pour concevoir le montage RF, on a également utilisé le meme d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
    [Hardware.kicad_sch]
2026-05-07 [Création de symbole, importation d'empreinte et Model 3D du filtre DLF162500LT-5028A1 depuis SnapMagic ] le filtre DLF162500LT-5028A1 n'a pas de modèle de symbole, donc je l'ai construite et puis j'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
    [DLF162500LT-5028A1--3DModel-STEP-269445.STEP, DLF162500LT-5028A1.step, untitled.kicad_sch]
2026-05-07 [BOOT] : Pour que la carte fonctionne bien, on met une résistance pull down à PH3_BOOT, ce qui permet au microcontroleur de continuer son execution normalement
    [Hardware.kicad_sch, untitled.kicad_sch]
2026-05-07 [Montage USB] : Montage de l'USB type C avec une protection ESD La protection ESD utilisé ici est l'USBLC6-2SC6 et le document pdf utilisé ici donne des indications sur comment le branché et sur son 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
    [usb.kicad_sch]
2026-05-07 [Hierachisation] hierachisation de la schématique et ajout de l'USB
    [Hardware.kicad_sch, untitled.kicad_sch]
2026-05-07 [Alimentation de la Carte]: Source provient de l'USB L'USB fournit une tension d'alimentation de 5V, et pour l'exploiter j'utilise un régulateur de tension stable en 3.3V. Le régulateur utilisé est l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
    [untitled.kicad_sch, usb.kicad_sch]
2026-05-07 [Doc]: Datasheet du regulateur qui donne des explications quant au montage. On peut utiliser une capacité de min 1uF, donc moi j'ai utilisé une de 4.7uF
2026-05-08 [Doc]: Documentation du capteur BME280 La documentation de ce capteur permet de réaliser le montage convennable et d'obtenir l'adresse I2C du capteur. Cette adresse est 0x77.
2026-05-08 [Realisation] : Regulateur de Tension, Capteur BME280, Buzzer, MQ2 et Leds indicateurs.
    Dans cette phase, j'ai réalisé les montages suivantes ;
    Regulateur de Tension : La tension d'alimentation du système vient de
    l'USB, donc en utilisant un regulateur de tension, on parvient à
    abaisser la tension à 3.3V
    Capteur BME280 : Le montage est réalisé comme recommandé par le
    fabricant Bosch. En y précisant les résistance pull up pour le protocol
    I2C.
    Buzzer : Le buzzer va servir d'alerte en raisonnant.
    Pour ce montage on utilise un transistor NPN pour amplifier le courant.
    MQ2 : Pour ce capteur, on utilise des éléments traversant et de ce fait,
    on va juste souder le composant à la carte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
    [Hardware.kicad_sch, untitled.kicad_sch, usb.kicad_sch]
2026-05-11 [RECOVERY FILE ] : La schématique RF n'était pas sauvegarder, donc elle a été perdu sous KICAD, mais j'ai pu l'avoir avec git au commit b7ce921fafebfe8b7fab3bae224a219c4f653a9d
    [RF.kicad_sch]
2026-05-11 [EXECUTION ERC] : Le check électrique a bien marché sauf une erreur persistante sur VLXSMPS ce qui est un défaut du symbole créé et non du montage de découplage proposé par ST Microelectronics
    [RF.kicad_sch, usb.kicad_sch]
2026-05-11 [FOOTPRINT ASSIGNMENT] : Ajout des footprints à chaque élément
    [Hardware.kicad_sch, RF.kicad_sch, usb.kicad_sch]
2026-05-11 [FOOTPRINT ASSIGNMENT] : J'ai ajouté le +5V flag de l'USB, j'ai ajouté des labels pour avoir un netclass plus consistent
    [Hardware.kicad_sch, RF.kicad_sch, usb.kicad_sch]
2026-05-12 [VERIFICATION, CORRECTION DES FOOTPRINTS ET MODELES 3D, ET ETABLISSEMENT DES REGLES DE DESIGN DU PCB]
    Le but de cette partie est de démarrer la phase du routage PCB.
    Je concois un PCB 4 couches ici, et il y'a des montages hyperfrequences
    donc il faut prendre en compte l'impédence de la ligne dans le design.
    Il y'a également la ligne USB qui doit aussi etre une ligne 50 Ohm
    adapté avec une impédance différentielle de 90 Ohm.
    Une phase essentielle a été de calculer la largeur de la piste dans les
    deux cas en utilisant les formules mathématique fournit par PCB Way
    design. Le but ici est de trouver la largeur de la piste permettant
    d'obtenir une impédance de ligne de 50 Ohm pour le mon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
    [CM8V-T1A-32.768KHZ-7PF-10PPM-TA-QC.STEP, Hardware.kicad_pcb, Hardware.kicad_sch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]
2026-05-13 [PLACEMENT DES COMPOSANT ET DIMENSIONNEMENT] : Avant de désigner le type de signal à chaque couche et commencer le routage, j'ai d'abord commencer par organiser les composants selon la schématique et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
    [Hardware.kicad_pcb, Hardware.kicad_sch, RF.kicad_sch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]
2026-05-13 [CORRECTION DES ERREURS SOLDER MASK] : Correction et attribution des valeurs de solder mask avec les valeurs correct de PCB Way
    [Hardware.kicad_pcb]
2026-05-13 [ROUTAGE ET CONTROL DRC] : J'ai routé la carte sur 4 couches. F.cu layer : c'est la prémière couche In1.cu layer: c'est le plan de masse In2.cu layer : c'est le plan de tension 3.3V B.cu layer : c'es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
    J'ai routé le PCB ensuite,j'ai effectué le Test DRC, puis j'ai corrigé
    les bug manifeste.
    [Hardware.kicad_pcb, RF.kicad_sch]
2026-05-13 [ANNOTATION DU DESIGN]: Annotation des module present sur la carte
    [Hardware.kicad_pcb]
2026-05-14 [Bill of Materials(BOM)]: Remplissage des informations tels que : manufacturer part number, manufacturer et la documentation du composant concerné. le BOM sera envoyé avec le fichier Geber au fabrica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
    [Hardware.kicad_sch, Hardware.xlsx, RF.kicad_sch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]
2026-05-14 [PREPARATION DES FICHIERS DE COMMANDES] : Generation de fichier de placement et de fichier gebers. J'ai généré le fichier de placement des composants selon l'origine de la grille. J'ai également géné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
    [Hardware-B_Cu.gbr, Hardware-B_Mask.gbr, Hardware-B_Paste.gbr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]
2026-05-14 [DOCUMENTATION] : Ajout des schémas explicatives dans le README.md
2026-05-15 [CORRECCTION DU PCB] : J'ai corrigé le PCB après avoir discuter avec le Fabricant PCB Way, j'ai corrigé le footprint de la capacité C14 avec ce qui correspond à ce qui est vendu par mouser electronic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
    [Hardware.kicad_pcb, Hardware.kicad_sch, RF.kicad_sch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]
2026-05-19 [MOD] : Changement de l'empreinte des connecteurs 01x04 pour celui de 2.54mm, et adjustement de la schématique du RF
    [Hardware.kicad_pcb]
2026-05-19 [VERSION 1] : Prémière version du geber, après discussion avec PCBWay, j'ai du faire des changements de la schématique du connecteur 01x04
    [Hardware BOM.csv, Hardware BOM.xlsx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]
2026-05-19 [Version Finale] : Après Correction et readjustement du PCB, voici la version produite
    [Hardware BOM.csv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]
2026-07-06 Manufacturer BOM corrections
    [T-3FR4W1075279A-2units-Hardware+BOM(2026-05-19).xls]
2026-08-12 [ VERSION FINALE APRES ERREUR DE SOUDAGE] Dans le premier fichier gerber envoyé à PCBWay, j'ai omis de mentionner que j'ai des composants traversant. Du coup, ils ont fabriqué la carte et après il ét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
    [Hardware-B_Adhesive.gbr, Hardware-B_Courtyard.gbr, Hardware-B_Cu.gbr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]
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2026-08-17 [FIRST TEST SUCCESSFUL] : Blinking 3 LEDS TO TEST MY LEDS
2026-08-19 [USB TO PC] : Envoie des données via USB J'ai parvenir à compiler le programme en enlevant usb.c des fichiers de compilation. ca a permis de compiler le projet. Donc, j'arrive à transmettre les donné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
2026-08-19 [ LED+USB+CAPTEUR BOSH WORKING] J'ai réussit à programmer le capteur bosh en utilisant le debuggage. en debuggant j'ai vu que le trimming était faux parcequ'il me renvoyait 1 pour signifier une erreu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
2026-08-19 [BUZZER WORKING] : Configuration du TIM2 CHANNEL 4 en PWM pour produire des sons de buzzer, donc j'ai réussit à faire des sons avec buzzer
    [SOFTWARE.ioc, main.c]
2026-08-21 [WORKING VERSION OF SYSTEM WITHOUT BLUETOOTH] BUZZER WORKS LEDS WORKS BME280 Works perfectly
    [SOFTWARE.ioc, app_conf.h]

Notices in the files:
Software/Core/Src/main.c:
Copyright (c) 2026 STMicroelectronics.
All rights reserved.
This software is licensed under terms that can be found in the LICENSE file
